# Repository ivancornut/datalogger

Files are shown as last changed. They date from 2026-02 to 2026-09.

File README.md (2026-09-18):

# Open Ecophysio Dataloggers
A competitive datalogger for use in environmental science. It is well adapted for work in remote locations with little access to networks. 

The big version of the datalogger is made to run on 12 or 24V lead batteries. This version has options to switch 12V or 5V loads.

The small version can run on 3 or 4 AA NiMh cells. It is made in a way that ensures very low consumption during sleep (few µAs). This gurantees around a year of logging before needing a battery change. 

Both versions have:
- a micro-SD card slot
- a very low-drift RTC for precise time-keeping
- battery voltage monitoring
- polarity and over-current protection

The interfacing software is compatible with windows, macOS and linux computers. It is made to be as simple to use as possible.

  * [Hardware](#hardware)
    + [Full size datalogger](#full-size-datalogger)
    + [Micro sized datalogger](#micro-sized-datalogger)
  * [Software](#software)
    + [On the computer](#on-the-computer)
    + [On the datalogger](#on-the-datalogger)

## Hardware
### Full size datalogger
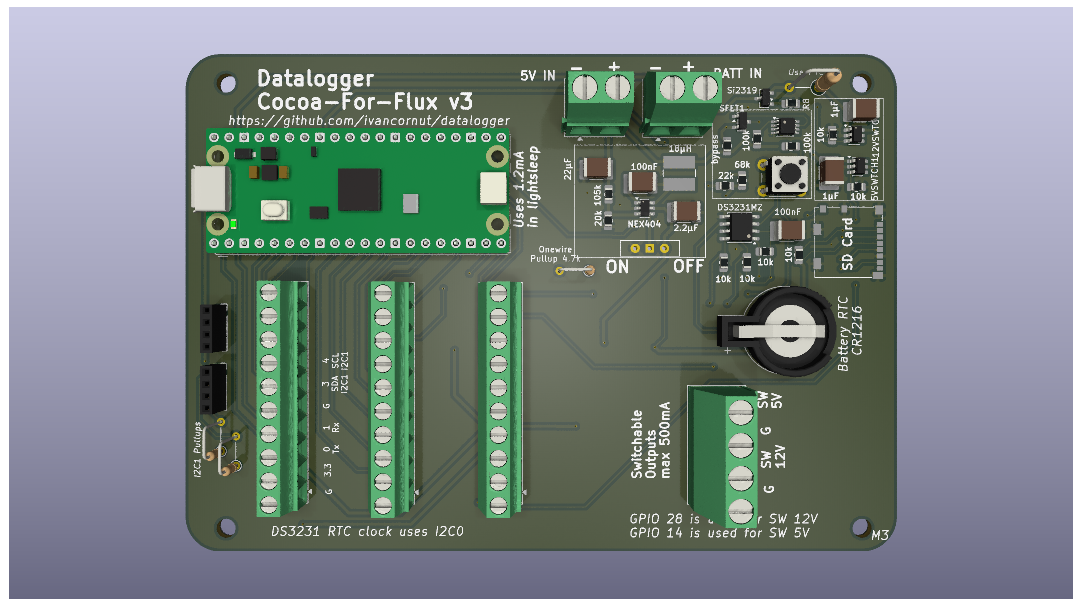
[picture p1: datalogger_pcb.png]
Finished datalogger PCB

We use a custom made PCB that integrates
- A battery input (usable with 12V lead batteries)
- a low consumption and high efficiency step-down converter that can convert 6-40V down to 5V
- a low-drift RTC clock
- An SD card slot
- two controllable power outputs of 5V and 12V (or battery voltage) using MOSFETs
- temperature corrected reference frequency generators from the RTC chip
- Qwiic compatible I2C and UART connectors
- A way to measure input battery voltage
### Micro sized datalogger
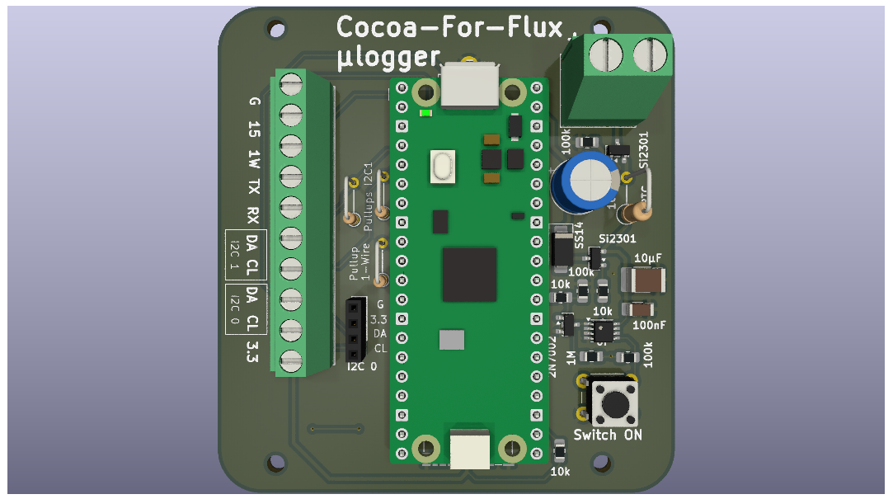
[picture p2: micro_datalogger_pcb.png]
3D rendering of datalogger PCB

This is a miniaturized version of the big pcb when size is a constraint. It pushed all the power and clock circuitry beneath the Pi Pico.
It lacks some functionality of the bigger version such as the controllable power outputs and the full shutdown circuitry. 

## Software
### On the computer
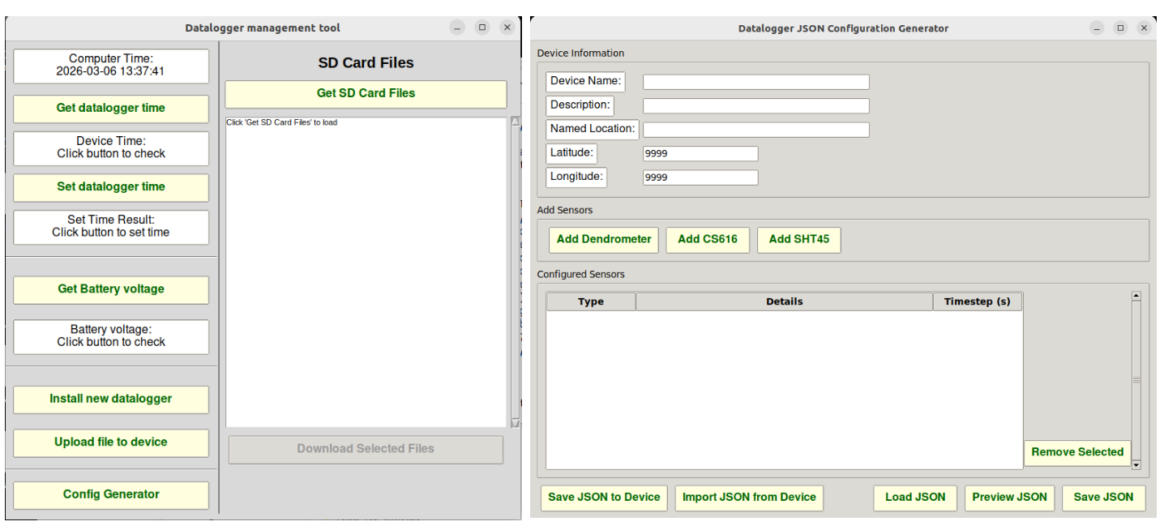
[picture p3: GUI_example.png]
Examples of interefacing GUIs

We use two GUIs on the computer:
- one that generates the json configuration file for the datalogger
- one that enables communication with the datalogger to update the clock and download files from the SD card

The datalogger management GUI also allows you to setup the datalogger with all the necessary libraries and config files to start datalogging right away.
#### Windows installation of the management GUI
The graphical user interface to perform some interfacing functions was made to be as easy to use as possible. For windows an executable file was created by using the pyinstaller library. 

To run on windows you first need to install python on your computer. You can install it easily from the windows store.
Then open up the powershell:
```
pip install mpremote
```
That should do the trick and you can just run the full_management_gui.exe in the Software/computer folder. 
#### Linux machine
You just need to install the mpremote tool. 
```
pip install mpremote
```
And then go to the folder containing full_management_gui.py: 
```
python full_management_gui.py
```

### On the datalogger
We use two modules. The datalogger module and the sensor module.

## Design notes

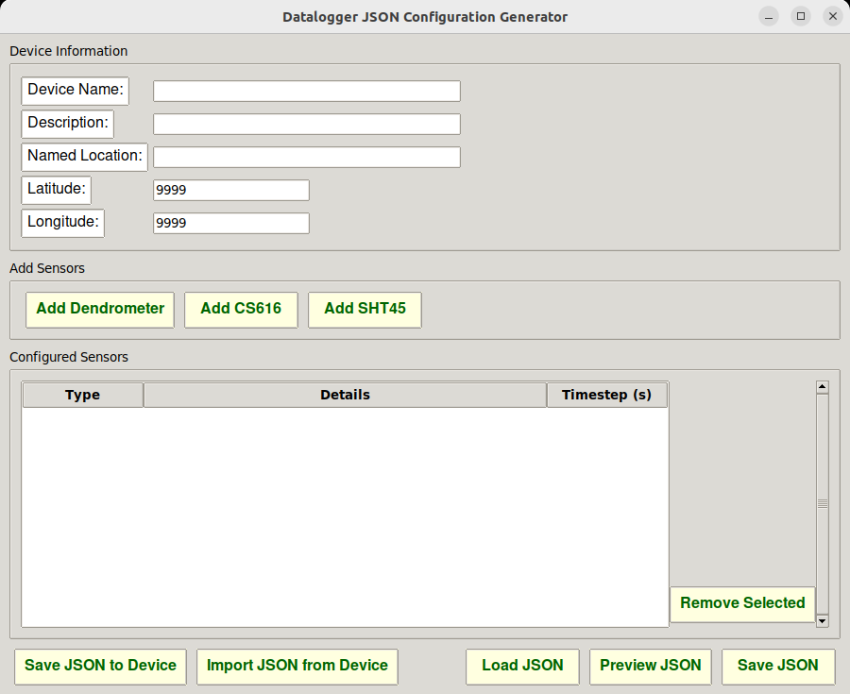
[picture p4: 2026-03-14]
config_ex.png

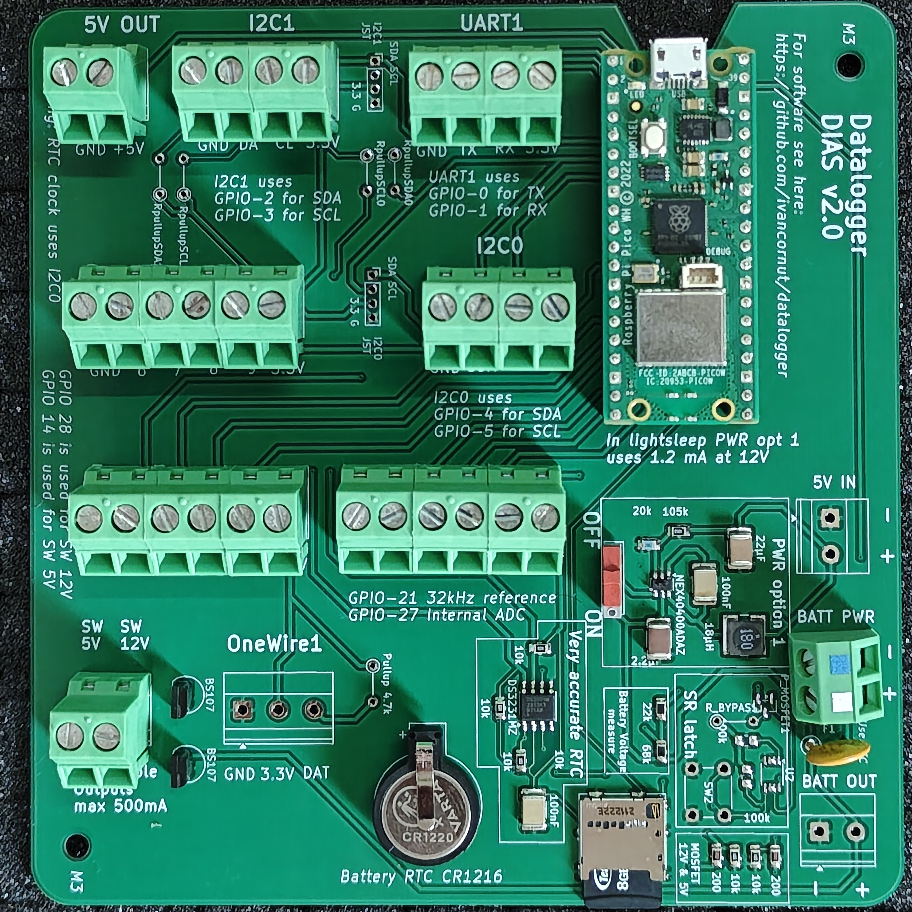
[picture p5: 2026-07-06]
datalogger_real.jpg

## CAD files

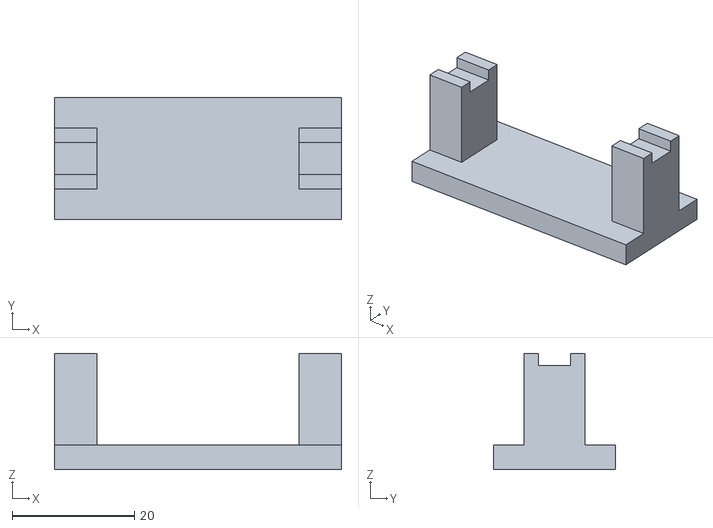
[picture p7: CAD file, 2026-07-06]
Hardware/sensors/temperature/temp_small/programmer_holder.stl
47.0 x 20.0 x 19.0

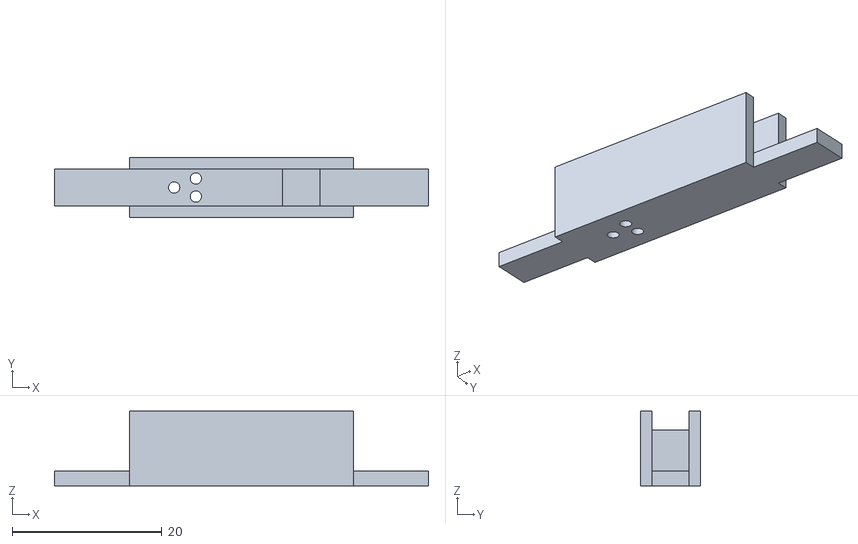
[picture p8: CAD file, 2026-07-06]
Hardware/sensors/temperature/temp_small/programmer.stl
50.0 x 8.00 x 10.0

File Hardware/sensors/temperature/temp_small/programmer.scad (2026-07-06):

include <BOSL2/std.scad>
difference(){
    union(){
    translate([0,0,10/2-1]){
        difference(){
            cuboid([30,8,10]);
            translate([0,0,2]){
                cuboid([31,5,10]);
            }
        }
    }
    cuboid([50,5,2]);
        translate([8,0,5.5/2+2/2]){
            cuboid([5,5,5.5]);
        }
    }
    translate([-9,0,0]){
        cyl(d = 1.5,h = 30,$fn = 100);
    }
    translate([-9+2.9,-2.4/2,0]){
        cyl(d = 1.5,h = 30,$fn = 100);
    }
    translate([-9+2.9,2.4/2,0]){
        cyl(d = 1.5,h = 30,$fn = 100);
    }
}

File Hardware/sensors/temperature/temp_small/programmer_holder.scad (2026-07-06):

include <BOSL2/std.scad>

union(){
    cuboid([47,20,4])
    translate([20,0,15/2+2]){
        difference(){
            cuboid([7,10,15]);
            translate([0,0,15/2-2/2]){
                cuboid([10,5.2,2]);
            }
        }
    }
    translate([-20,0,15/2+2]){
        difference(){
            cuboid([7,10,15]);
            translate([0,0,15/2-2/2]){
                cuboid([10,5.2,2]);
            }
        }
    }
}

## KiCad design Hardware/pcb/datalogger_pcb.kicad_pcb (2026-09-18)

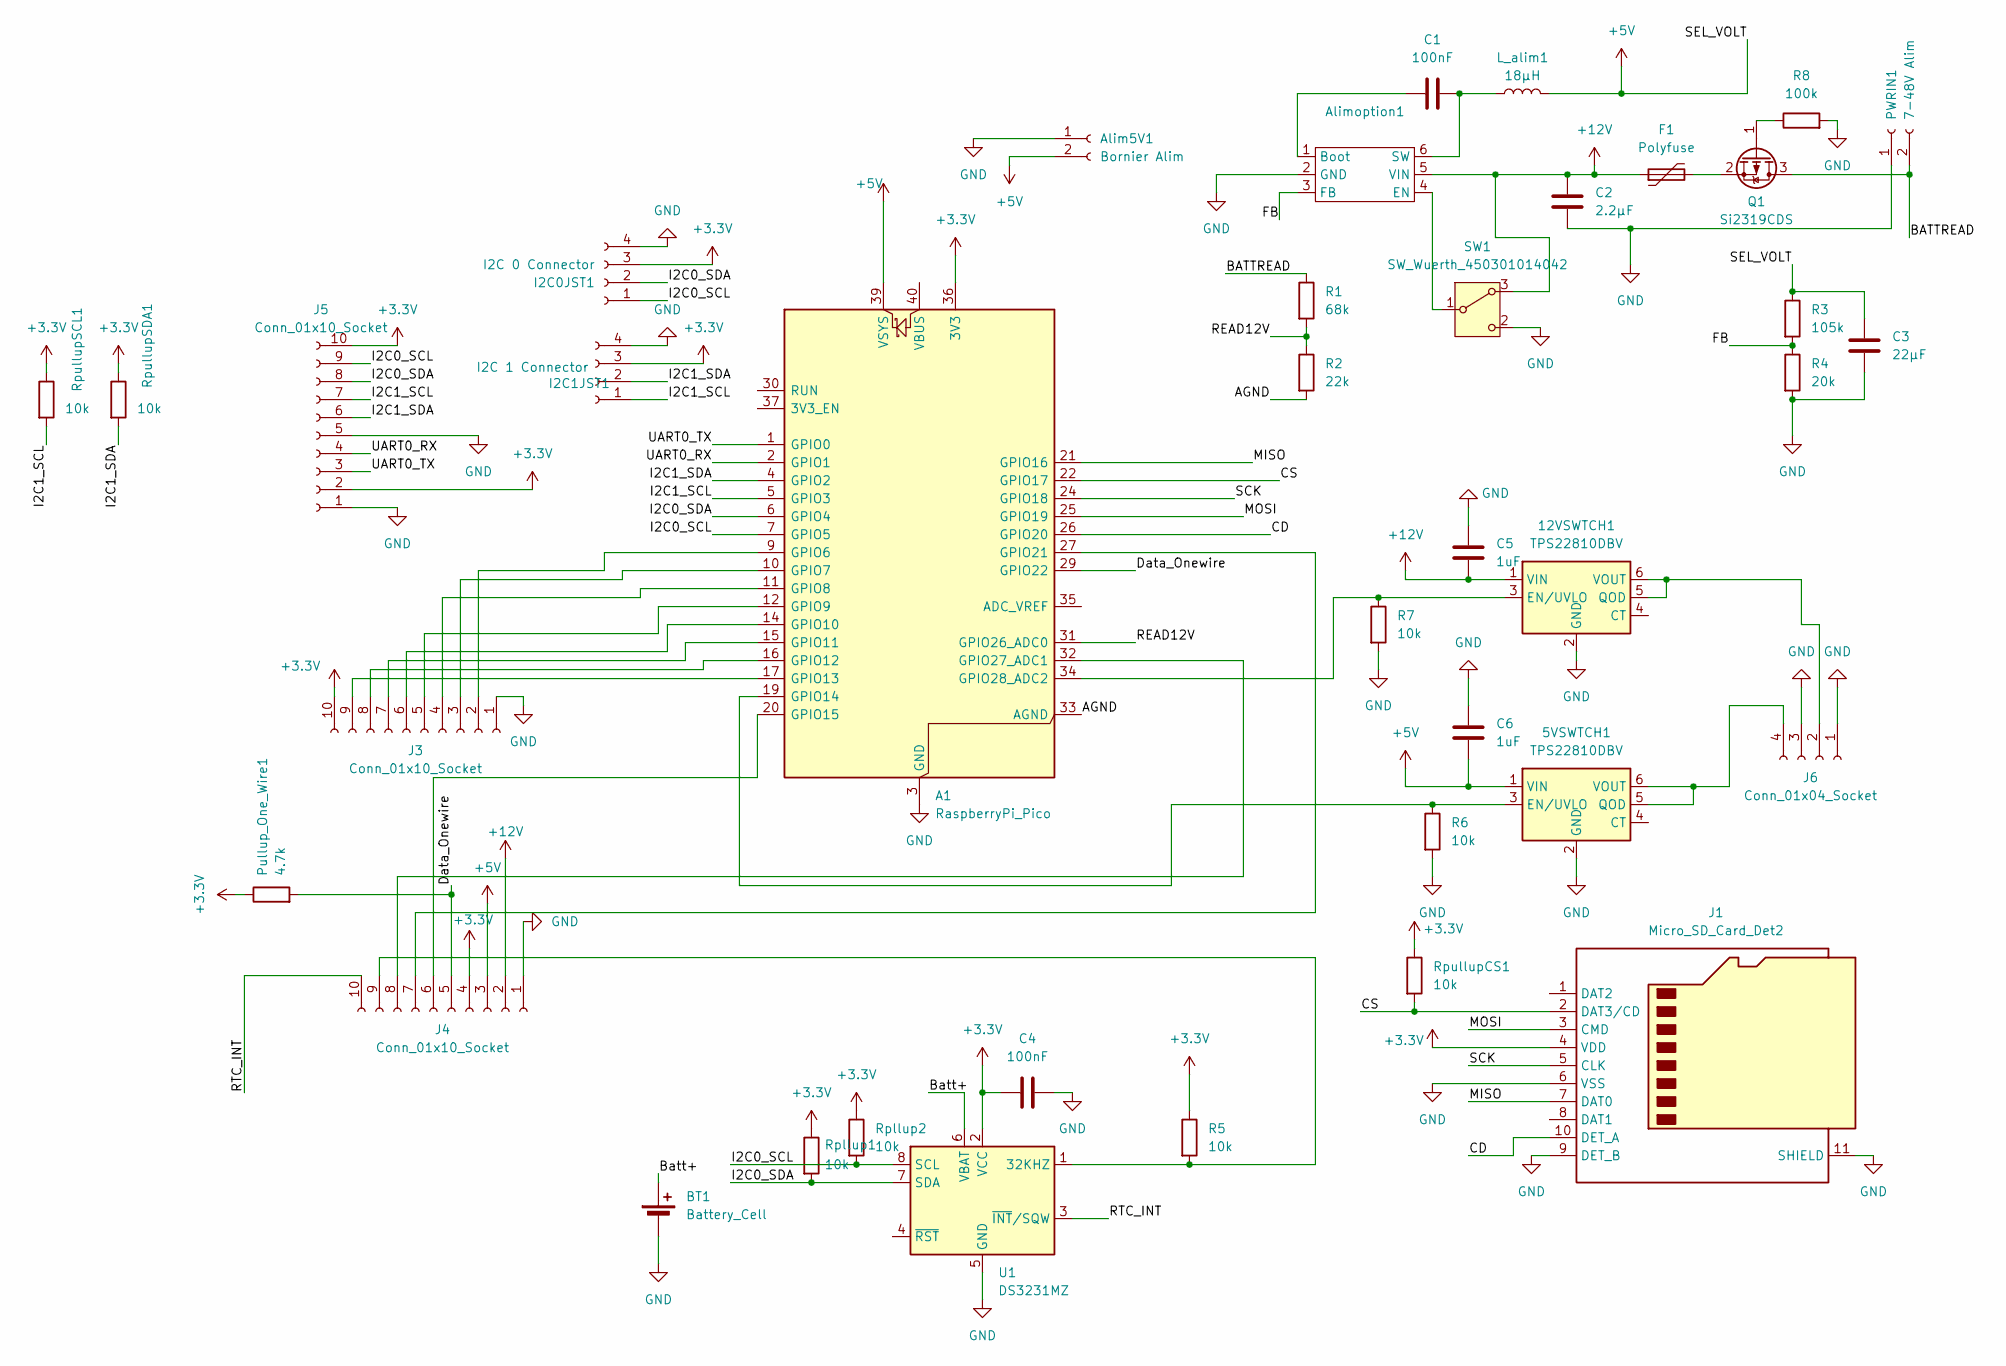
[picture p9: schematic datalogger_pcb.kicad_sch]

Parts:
5VSWTCH1, 12VSWTCH1: TPS22810DBV; SOT-23-6
A1: RaspberryPi_Pico; pi_pico_only_pins
Alim5V1: Bornier Alim; TerminalBlock_Phoenix_MKDS-1,5-2-5.08_1x02_P5.08mm_Horizont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
Alimoption1: TSOT-23-6_NEX
BT1: Battery_Cell; BatteryHolder_Keystone_500
C1, C4: 100nF; C_1812_4532Metric_Pad1.57x3.40mm_HandSolder
C2: 2.2µF; C_1812_4532Metric_Pad1.57x3.40mm_HandSolder
C3: 22µF; C_1812_4532Metric_Pad1.57x3.40mm_HandSolder
C5, C6: 1uF; C_1812_4532Metric_Pad1.57x3.40mm_HandSolder
F1: Polyfuse; R_Axial_DIN0207_L6.3mm_D2.5mm_P5.08mm_Vertical
I2C0JST1: I2C 0 Connector; PinSocket_1x04_P2.00mm_Vertical
I2C1JST1: I2C 1 Connector; PinSocket_1x04_P2.00mm_Vertical
J1: Micro_SD_Card_Det2; microSD_HC_Molex_104031-0811
J3, J4, J5: Conn_01x10_Socket; TerminalBlock_Phoenix_MKDS-1-10-3.81_1x10_P3.81mm_Horizontal
J6: Conn_01x04_Socket; TerminalBlock_Phoenix_MKDS-1,5-4-5.08_1x04_P5.08mm_Horizont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
L_alim1: 18µH; L_TracoPower_TCK-047_5.2x5.8mm
PWRIN1: 7-48V Alim; TerminalBlock_Phoenix_MKDS-1,5-2-5.08_1x02_P5.08mm_Horizont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
Pullup_One_Wire1: 4.7k; R_Axial_DIN0204_L3.6mm_D1.6mm_P5.08mm_Vertical
Q1: Si2319CDS; SOT-23
R1: 68k; R_0805_2012Metric_Pad1.20x1.40mm_HandSolder
R2: 22k; R_0805_2012Metric_Pad1.20x1.40mm_HandSolder
R3: 105k; R_0805_2012Metric_Pad1.20x1.40mm_HandSolder
R4: 20k; R_0805_2012Metric_Pad1.20x1.40mm_HandSolder
R5, R6, R7: 10k; R_0805_2012Metric_Pad1.20x1.40mm_HandSolder
R8: 100k; R_0805_2012Metric_Pad1.20x1.40mm_HandSolder
Rpllup1, Rpllup2: 10k; R_0805_2012Metric_Pad1.20x1.40mm_HandSolder
RpullupCS1: 10k; R_0805_2012Metric_Pad1.20x1.40mm_HandSolder
RpullupSCL1: 10k; R_Axial_DIN0204_L3.6mm_D1.6mm_P5.08mm_Vertical
RpullupSDA1: 10k; R_Axial_DIN0204_L3.6mm_D1.6mm_P5.08mm_Vertical
SW1: SW_Wuerth_450301014042; SW_Slide-03_Wuerth-WS-SLTV_10x2.5x6.4_P2.54mm
U1: DS3231MZ; SOIC-8_3.9x4.9mm_P1.27mm

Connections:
+3.3V: A1.36 (3V3), C4.1, I2C0JST1.3, I2C1JST1.3, J1.4 (VDD), J3.10, J4.4, J5.2, J5.10, Pullup_One_Wire1.1, R5.1, Rpllup1.1, Rpllup2.1, RpullupCS1.1, RpullupSCL1.1, RpullupSDA1.1, U1.2 (VCC)
+5V: 5VSWTCH1.1 (VIN), A1.39 (VSYS), Alim5V1.2, C3.1, C6.2, J4.3, L_alim1.2, R3.1
+12V: 12VSWTCH1.1 (VIN), Alimoption1.5 (VIN), C2.1, C5.2, F1.1, J4.2, SW1.3 (A)
/AGND: A1.33 (AGND), R2.2
/BATTREAD: PWRIN1.2, Q1.3 (D), R1.1
/Batt+: BT1.1 (+), U1.6 (VBAT)
/CD: A1.26 (GPIO20), J1.10 (DET_A)
/CS: A1.22 (GPIO17), J1.2 (DAT3/CD), RpullupCS1.2
/Data_Onewire: A1.29 (GPIO22), J4.5, Pullup_One_Wire1.2
/FB: Alimoption1.3 (FB), R3.2, R4.1
/I2C0_SCL: A1.7 (GPIO5), I2C0JST1.1, J5.9, Rpllup2.2, U1.8 (SCL)
/I2C0_SDA: A1.6 (GPIO4), I2C0JST1.2, J5.8, Rpllup1.2, U1.7 (SDA)
/I2C1_SCL: A1.5 (GPIO3), I2C1JST1.1, J5.7, RpullupSCL1.2
/I2C1_SDA: A1.4 (GPIO2), I2C1JST1.2, J5.6, RpullupSDA1.2
/MISO: A1.21 (GPIO16), J1.7 (DAT0)
/MOSI: A1.25 (GPIO19), J1.3 (CMD)
/READ12V: A1.31 (GPIO26_ADC0), R1.2, R2.1
/RTC_INT: J4.10, U1.3 (~INT/SQW)
/SCK: A1.24 (GPIO18), J1.5 (CLK)
/UART0_RX: A1.2 (GPIO1), J5.4
/UART0_TX: A1.1 (GPIO0), J5.3
GND: 5VSWTCH1.2 (GND), 12VSWTCH1.2 (GND), A1.3 (GND), A1.8 (GND), A1.13 (GND), A1.18 (GND), A1.23 (GND), A1.28 (GND), A1.38 (GND), Alim5V1.1, Alimoption1.2 (GND), BT1.2 (-), C2.2, C3.2, C4.2, C5.1, C6.1, I2C0JST1.4, I2C1JST1.4, J1.6 (VSS), J1.9 (DET_B), J1.11 (SHIELD), J3.1, J4.1, J5.1, J5.5, J6.1, J6.3, PWRIN1.1, R4.2, R6.2, R7.2, R8.2, SW1.2 (C), U1.5 (GND)
unnamed: 5VSWTCH1.3 (EN/UVLO), A1.19 (GPIO14), R6.1
unnamed: 5VSWTCH1.5 (QOD), 5VSWTCH1.6 (VOUT), J6.4
unnamed: 12VSWTCH1.3 (EN/UVLO), A1.34 (GPIO28_ADC2), R7.1
unnamed: 12VSWTCH1.5 (QOD), 12VSWTCH1.6 (VOUT), J6.2
unnamed: A1.9 (GPIO6), J3.2
unnamed: A1.10 (GPIO7), J3.3
unnamed: A1.11 (GPIO8), J3.4
unnamed: A1.12 (GPIO9), J3.5
unnamed: A1.14 (GPIO10), J3.6
unnamed: A1.15 (GPIO11), J3.7
unnamed: A1.16 (GPIO12), J3.8
unnamed: A1.17 (GPIO13), J3.9
unnamed: A1.20 (GPIO15), J4.6
unnamed: A1.27 (GPIO21), J4.7
unnamed: A1.32 (GPIO27_ADC1), J4.8
unnamed: Alimoption1.1 (Boot), C1.1
unnamed: Alimoption1.4 (EN), SW1.1 (B)
unnamed: Alimoption1.6 (SW), C1.2, L_alim1.1
unnamed: J4.9, R5.2, U1.1 (32KHZ)
unnamed: Q1.1 (G), R8.1
unnamed: F1.2, Q1.2 (S)

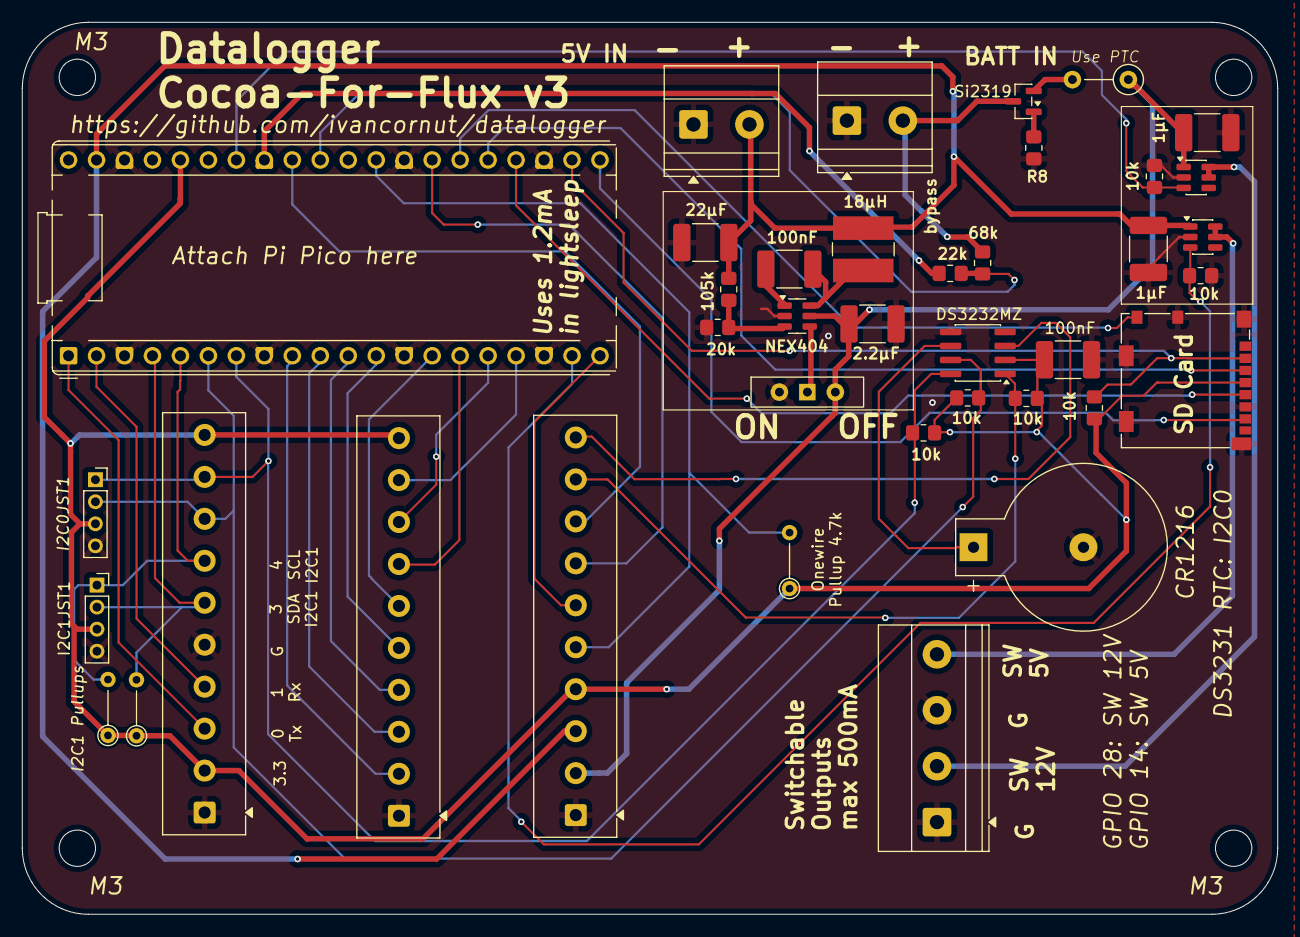
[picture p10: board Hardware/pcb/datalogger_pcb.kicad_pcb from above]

Board: 2 copper layers, 114.0 x 81.0 mm, 39 parts (0 on the bottom side), 43 nets.

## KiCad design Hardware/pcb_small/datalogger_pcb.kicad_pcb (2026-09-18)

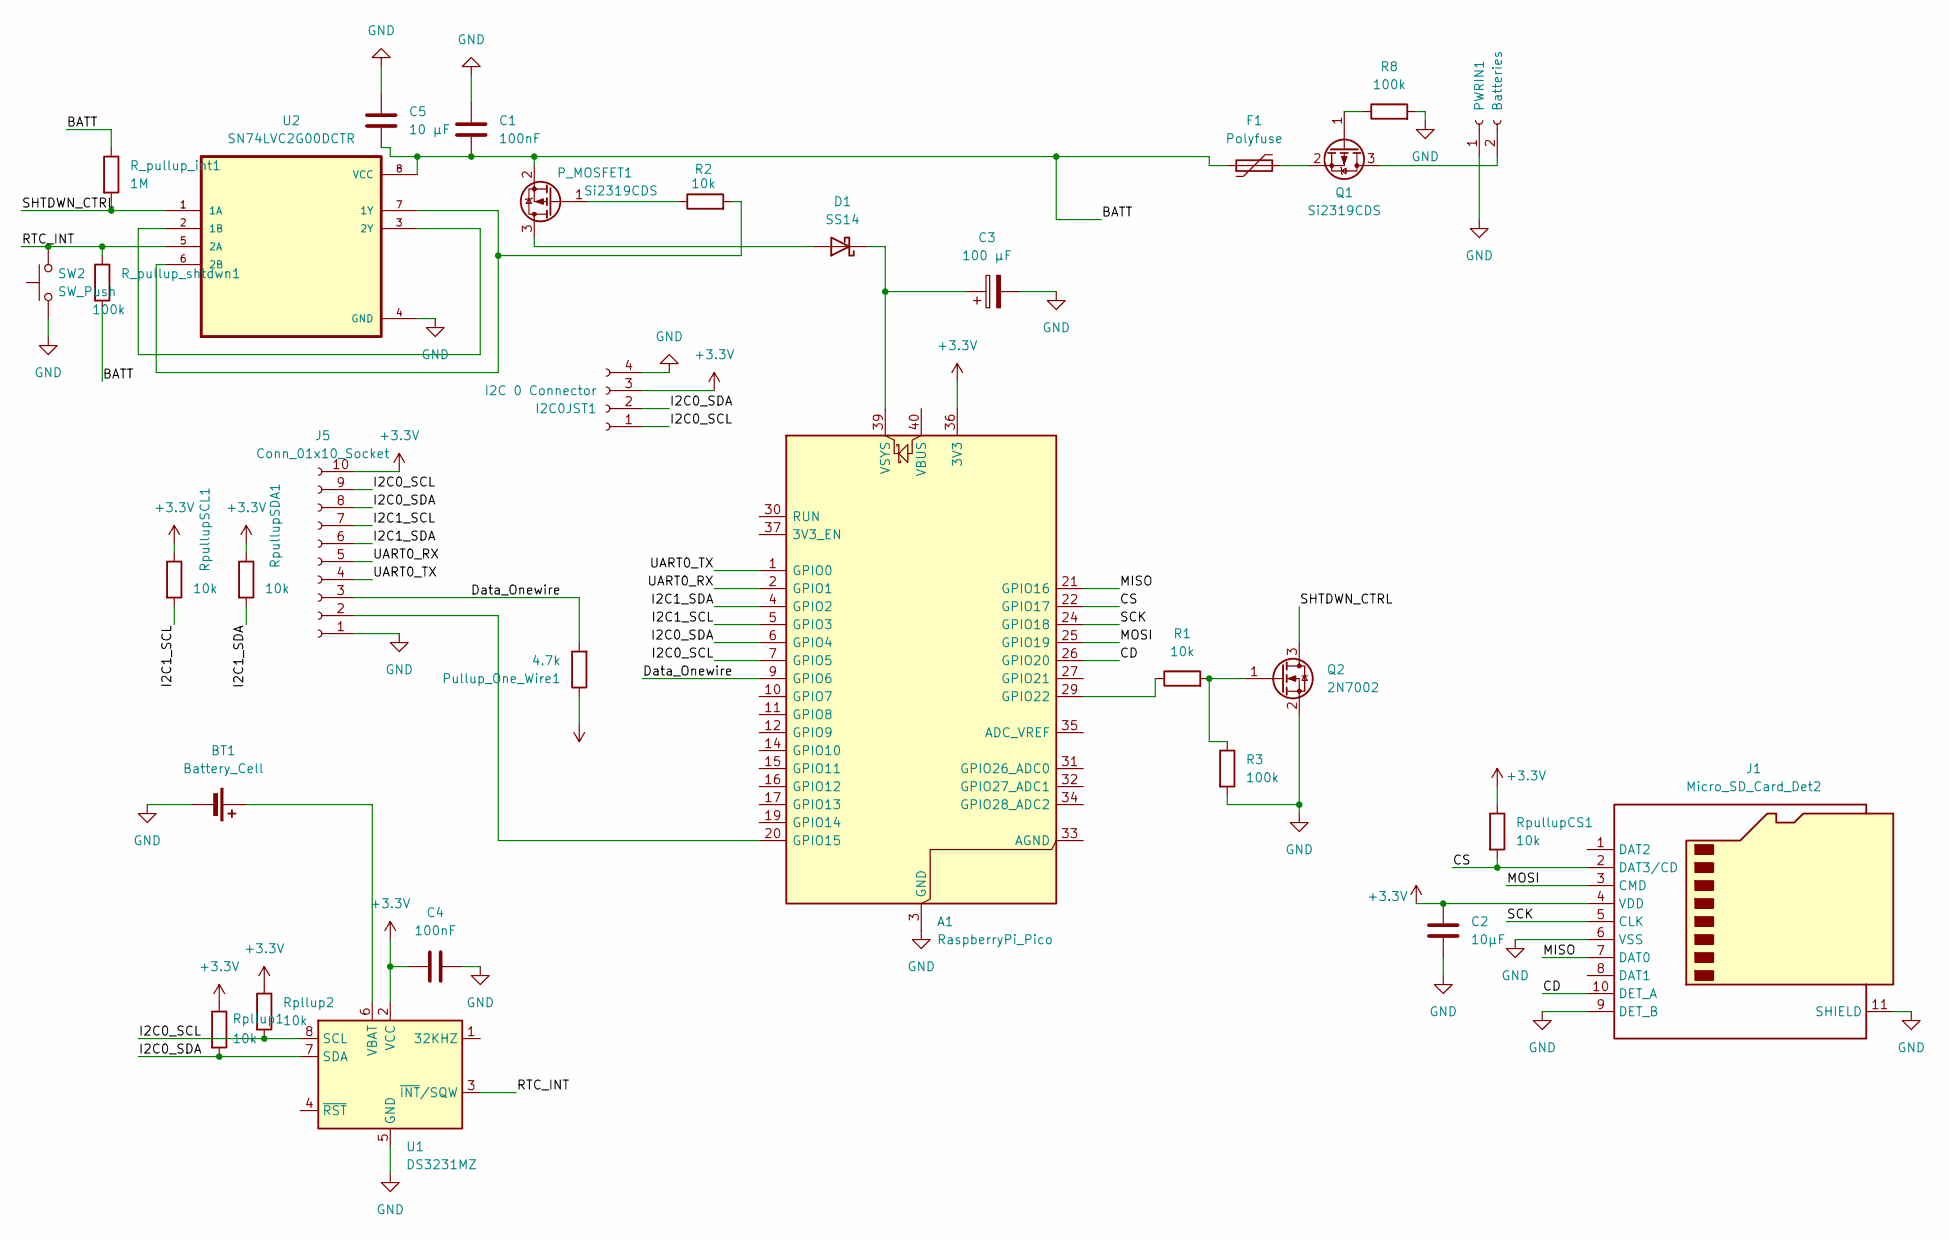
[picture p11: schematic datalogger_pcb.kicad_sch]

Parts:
A1: RaspberryPi_Pico; pi_pico_only_pins
BT1: Battery_Cell; BatteryHolder_Keystone_500
C1, C4: 100nF; C_1206_3216Metric_Pad1.33x1.80mm_HandSolder
C2: 10µF; C_1812_4532Metric_Pad1.57x3.40mm_HandSolder
C3: 100 µF; CP_Radial_D7.5mm_P2.50mm
C5: 10 µF; C_1812_4532Metric_Pad1.57x3.40mm_HandSolder
D1: SS14; D_SMA
F1: Polyfuse; R_Axial_DIN0207_L6.3mm_D2.5mm_P5.08mm_Vertical
I2C0JST1: I2C 0 Connector; PinSocket_1x04_P2.00mm_Vertical
J1: Micro_SD_Card_Det2; microSD_HC_Molex_104031-0811
J5: Conn_01x10_Socket; TerminalBlock_Phoenix_MKDS-1-10-3.81_1x10_P3.81mm_Horizontal
PWRIN1: Batteries; TerminalBlock_Phoenix_MKDS-1,5-2-5.08_1x02_P5.08mm_Horizont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
P_MOSFET1: Si2319CDS; SOT-23
Pullup_One_Wire1: 4.7k; R_Axial_DIN0204_L3.6mm_D1.6mm_P5.08mm_Vertical
Q1: Si2319CDS; SOT-23
Q2: 2N7002; SOT-23
R1, R2: 10k; R_0805_2012Metric_Pad1.20x1.40mm_HandSolder
R3, R8: 100k; R_0805_2012Metric_Pad1.20x1.40mm_HandSolder
R_pullup_int1: 1M; R_0805_2012Metric_Pad1.20x1.40mm_HandSolder
R_pullup_shtdwn1: 100k; R_0805_2012Metric_Pad1.20x1.40mm_HandSolder
Rpllup1, Rpllup2: 10k; R_0805_2012Metric_Pad1.20x1.40mm_HandSolder
RpullupCS1: 10k; R_0805_2012Metric_Pad1.20x1.40mm_HandSolder
RpullupSCL1: 10k; R_Axial_DIN0204_L3.6mm_D1.6mm_P5.08mm_Vertical
RpullupSDA1: 10k; R_Axial_DIN0204_L3.6mm_D1.6mm_P5.08mm_Vertical
SW2: SW_Push; SW_PUSH_6mm_H4.3mm
U1: DS3231MZ; SOIC-8_3.9x4.9mm_P1.27mm
U2: SN74LVC2G00DCTR; SSOP-8_2.95x2.8mm_P0.65mm - SN74LVC2G00

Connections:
+3.3V: A1.36 (3V3), C2.1, C4.1, I2C0JST1.3, J1.4 (VDD), J5.10, Pullup_One_Wire1.1, Rpllup1.1, Rpllup2.1, RpullupCS1.1, RpullupSCL1.1, RpullupSDA1.1, U1.2 (VCC)
/BATT: C1.1, C5.1, F1.1, P_MOSFET1.2 (S), R_pullup_int1.1, R_pullup_shtdwn1.2, U2.8 (VCC)
/CD: A1.26 (GPIO20), J1.10 (DET_A)
/CS: A1.22 (GPIO17), J1.2 (DAT3/CD), RpullupCS1.2
/Data_Onewire: A1.9 (GPIO6), J5.3, Pullup_One_Wire1.2
/I2C0_SCL: A1.7 (GPIO5), I2C0JST1.1, J5.9, Rpllup2.2, U1.8 (SCL)
/I2C0_SDA: A1.6 (GPIO4), I2C0JST1.2, J5.8, Rpllup1.2, U1.7 (SDA)
/I2C1_SCL: A1.5 (GPIO3), J5.7, RpullupSCL1.2
/I2C1_SDA: A1.4 (GPIO2), J5.6, RpullupSDA1.2
/MISO: A1.21 (GPIO16), J1.7 (DAT0)
/MOSI: A1.25 (GPIO19), J1.3 (CMD)
/RTC_INT: R_pullup_shtdwn1.1, SW2.2, U1.3 (~INT/SQW), U2.5 (2A)
/SCK: A1.24 (GPIO18), J1.5 (CLK)
/SHTDWN_CTRL: Q2.3 (D), R_pullup_int1.2, U2.1 (1A)
/UART0_RX: A1.2 (GPIO1), J5.5
/UART0_TX: A1.1 (GPIO0), J5.4
GND: A1.3 (GND), A1.8 (GND), A1.13 (GND), A1.18 (GND), A1.23 (GND), A1.28 (GND), A1.38 (GND), BT1.2 (-), C1.2, C2.2, C3.2, C4.2, C5.2, I2C0JST1.4, J1.6 (VSS), J1.9 (DET_B), J1.11 (SHIELD), J5.1, PWRIN1.1, Q2.2 (S), R3.2, R8.2, SW2.1, U1.5 (GND), U2.4 (GND)
unnamed: A1.20 (GPIO15), J5.2
unnamed: A1.29 (GPIO22), R1.1
unnamed: A1.39 (VSYS), C3.1, D1.1 (K)
unnamed: BT1.1 (+), U1.6 (VBAT)
unnamed: D1.2 (A), P_MOSFET1.3 (D)
unnamed: PWRIN1.2, Q1.3 (D)
unnamed: P_MOSFET1.1 (G), R2.1
unnamed: Q1.1 (G), R8.1
unnamed: F1.2, Q1.2 (S)
unnamed: Q2.1 (G), R1.2, R3.1
unnamed: U2.2 (1B), U2.3 (2Y)
unnamed: R2.2, U2.6 (2B), U2.7 (1Y)

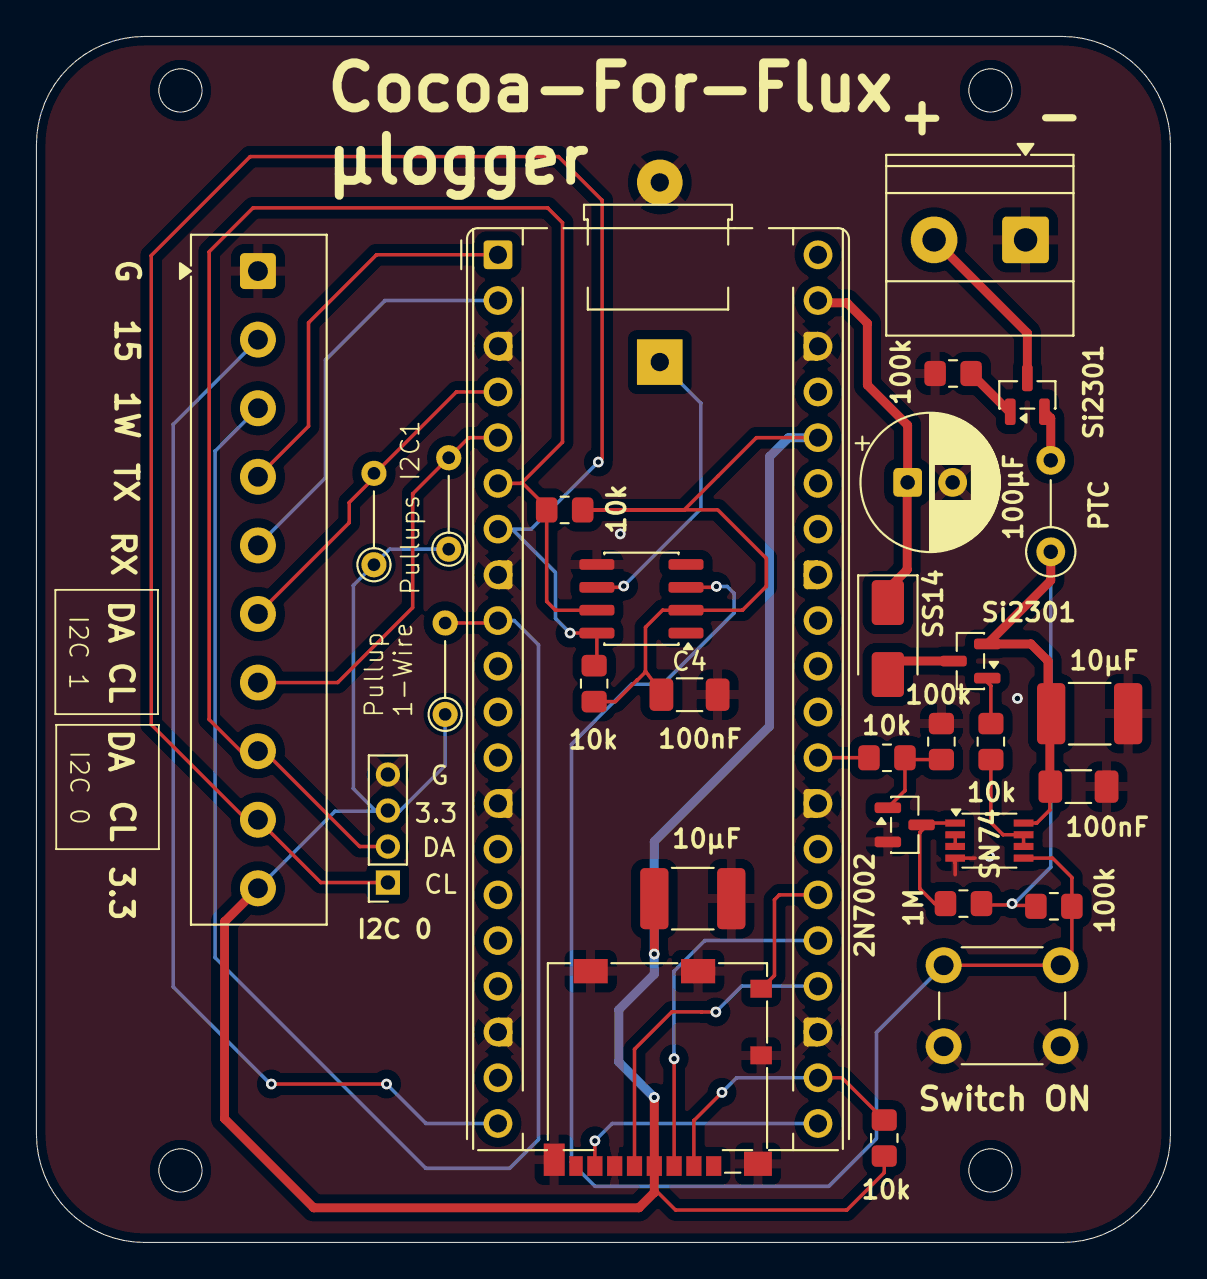
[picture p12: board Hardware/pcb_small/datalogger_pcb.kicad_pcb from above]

Board: 2 copper layers, 63.0 x 67.0 mm, 31 parts (1 on the bottom side), 29 nets.

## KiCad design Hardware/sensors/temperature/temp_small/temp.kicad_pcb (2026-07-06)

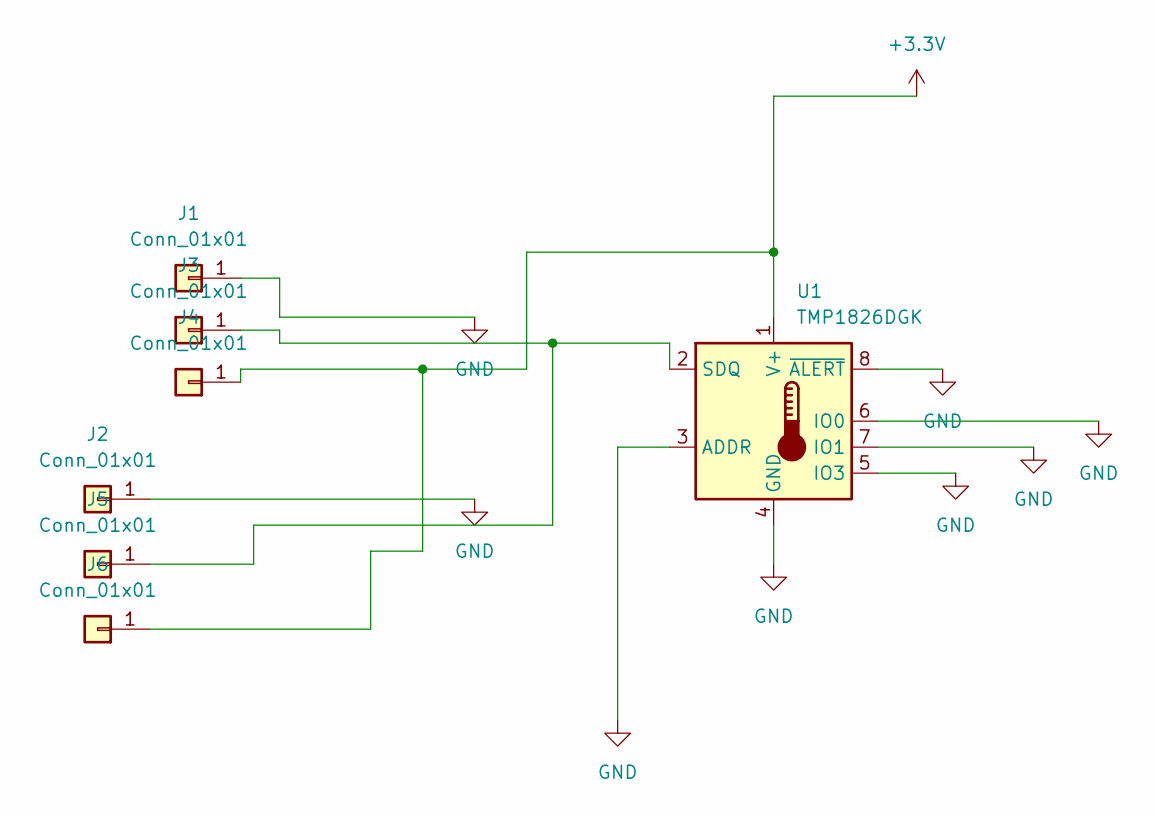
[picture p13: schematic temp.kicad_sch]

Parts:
J1, J2, J3, J4, J5, J6: Conn_01x01; PinHeader_1x01_P1.27mm_Vertical
U1: TMP1826DGK; VSSOP-8_3x3mm_P0.65mm

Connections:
+3.3V: J4.1, J6.1, U1.1 (V+)
GND: J1.1, J2.1, U1.3 (ADDR), U1.4 (GND), U1.5 (IO3), U1.6 (IO0), U1.7 (IO1), U1.8 (~ALERT)
unnamed: J3.1, J5.1, U1.2 (SDQ)

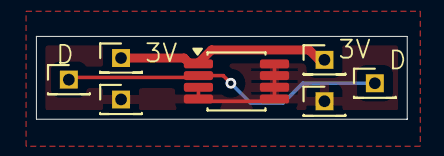
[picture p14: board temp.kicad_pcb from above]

Board: 2 copper layers, 20.6 x 4.6 mm, 7 parts (0 on the bottom side), 3 nets.

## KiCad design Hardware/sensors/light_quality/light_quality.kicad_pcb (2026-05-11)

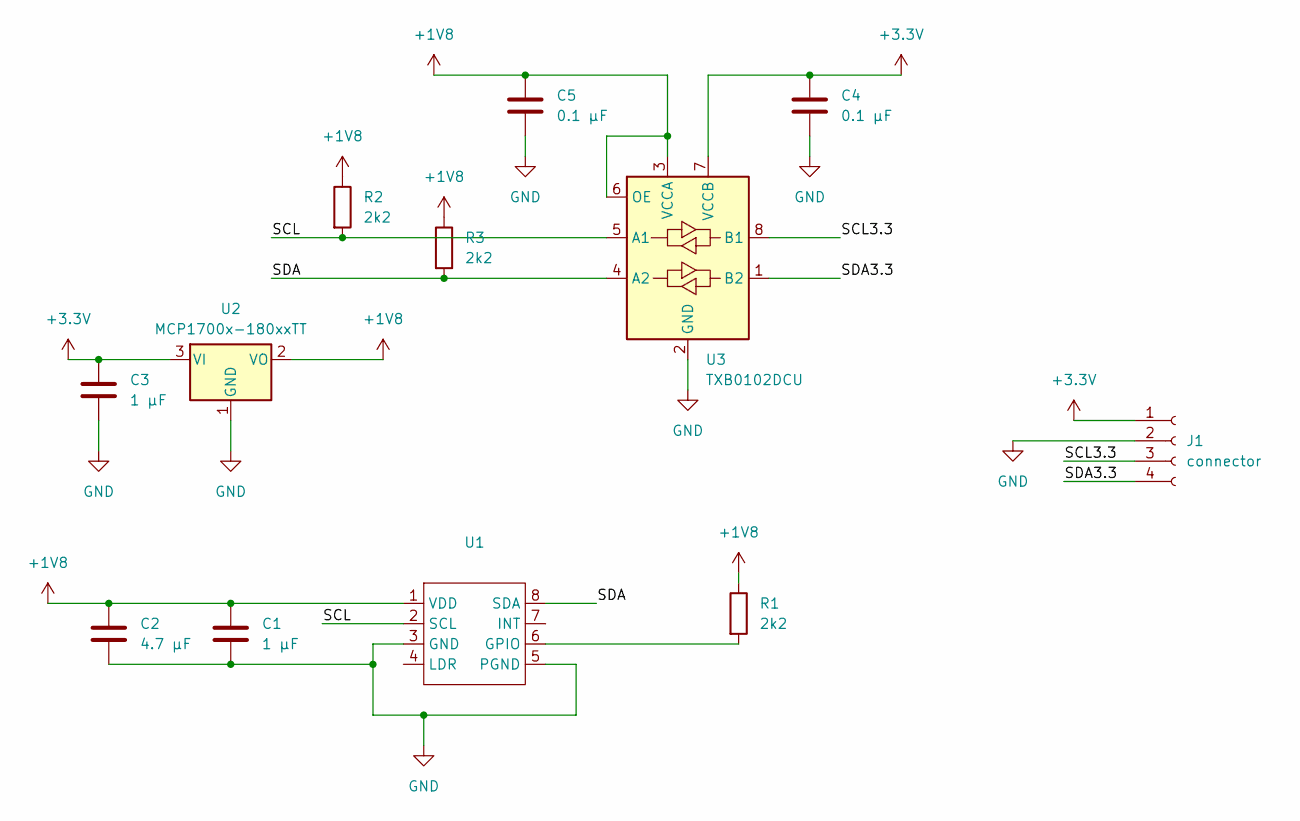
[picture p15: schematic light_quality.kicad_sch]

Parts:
C1, C3: 1 µF; C_0805_2012Metric_Pad1.18x1.45mm_HandSolder
C2: 4.7 µF; C_0805_2012Metric_Pad1.18x1.45mm_HandSolder
C4, C5: 0.1 µF; C_0805_2012Metric_Pad1.18x1.45mm_HandSolder
J1: connector; PinSocket_1x04_P2.00mm_Vertical
R1, R2, R3: 2k2; R_0805_2012Metric_Pad1.20x1.40mm_HandSolder
U1: AMS_OLGA-8_2x3.1mm_P0.8mm
U2: MCP1700x-180xxTT; SOT-23
U3: TXB0102DCU; VSSOP-8_2.3x2mm_P0.5mm

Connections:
+1V8: C1.1, C2.1, C5.1, R1.1, R2.1, R3.1, U1.1 (VDD), U2.2 (VO), U3.3 (VCCA), U3.6 (OE)
+3.3V: C3.1, C4.1, J1.1, U2.3 (VI), U3.7 (VCCB)
/SCL: R2.2, U1.2 (SCL), U3.5 (A1)
/SCL3.3: J1.3, U3.8 (B1)
/SDA: R3.2, U1.8 (SDA), U3.4 (A2)
/SDA3.3: J1.4, U3.1 (B2)
GND: C1.2, C2.2, C3.2, C4.2, C5.2, J1.2, U1.3 (GND), U1.5 (PGND), U2.1 (GND), U3.2 (GND)
unnamed: R1.2, U1.6 (GPIO)

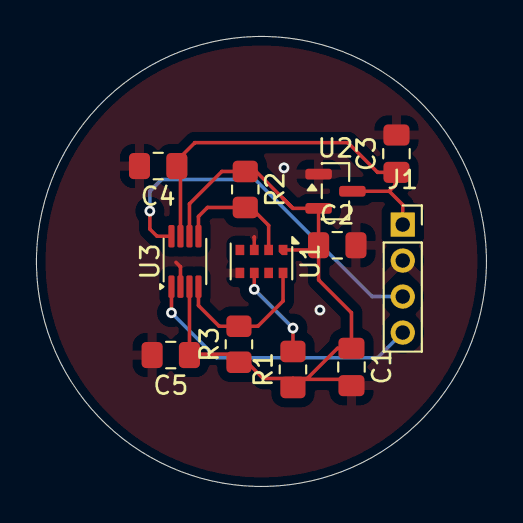
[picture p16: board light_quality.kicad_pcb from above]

Board: 2 copper layers, 25.0 x 25.0 mm, 12 parts (0 on the bottom side), 8 nets.

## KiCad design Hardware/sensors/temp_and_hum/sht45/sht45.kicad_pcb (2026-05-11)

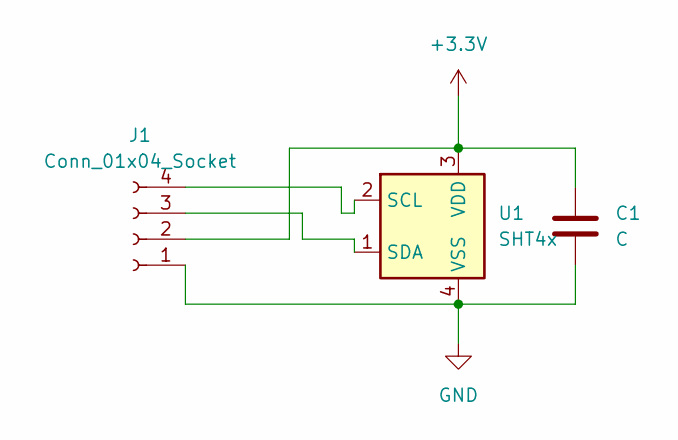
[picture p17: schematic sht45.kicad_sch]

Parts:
C1: C; C_0805_2012Metric_Pad1.18x1.45mm_HandSolder
J1: Conn_01x04_Socket; NS-Tech_Grove_1x04_P2mm_Vertical
U1: SHT4x; Sensirion_DFN-4_1.5x1.5mm_P0.8mm_SHT4x_NoCentralPad

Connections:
+3.3V: C1.1, J1.2, U1.3 (VDD)
GND: C1.2, J1.1, U1.4 (VSS)
unnamed: J1.3, U1.1 (SDA)
unnamed: J1.4, U1.2 (SCL)

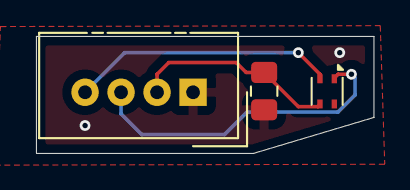
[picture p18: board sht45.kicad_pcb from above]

Board: 2 copper layers, 18.8 x 6.5 mm, 3 parts (0 on the bottom side), 4 nets.

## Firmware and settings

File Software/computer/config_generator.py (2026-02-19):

#!/usr/bin/env python3
"""
Datalogger JSON Configuration Generator
A tkinter GUI for creating JSON configuration files for dataloggers.
"""

import tkinter as tk
from tkinter import ttk, messagebox, filedialog
import json


class SensorDialog(tk.Toplevel):
    """Base class for sensor configuration dialogs."""
    
    def __init__(self, parent, title):
        super().__init__(parent)
        self.title(title)
        self.result = None
        self.transient(parent)
        self.grab_set()
        
        # Center the dialog
        self.geometry("+%d+%d" % (parent.winfo_rootx() + 50, parent.winfo_rooty() + 50))
        
        self.create_widgets()
        
        self.protocol("WM_DELETE_WINDOW", self.cancel)
        self.wait_window(self)
    
    def create_widgets(self):
        """Override in subclasses."""
        pass
    
    def validate(self):
        """Override in subclasses."""
        return True
    
    def ok(self):
        if self.validate():
            self.destroy()
    
    def cancel(self):
        self.result = None
        self.destroy()


class DendroDialog(SensorDialog):
    """Dialog for configuring dendrometer sensors."""
    
    def __init__(self, parent):
        self.name_entries = []
        self.excite_entries = []
        super().__init__(parent, "Add Dendrometer Sensor")
    
    def create_widgets(self):
        main_frame = ttk.Frame(self, padding="10")
        main_frame.pack(fill=tk.BOTH, expand=True)
        
        # I2C selection
        ttk.Label(main_frame, text="I2C Bus:").grid(row=0, column=0, sticky=tk.W, pady=2)
        self.i2c_var = tk.IntVar(value=0)
        i2c_frame = ttk.Frame(main_frame)
        i2c_frame.grid(row=0, column=1, sticky=tk.W, pady=2)
        ttk.Radiobutton(i2c_frame, text="0", variable=self.i2c_var, value=0).pack(side=tk.LEFT)
        ttk.Radiobutton(i2c_frame, text="1", variable=self.i2c_var, value=1).pack(side=tk.LEFT)
        
        # Address
        ttk.Label(main_frame, text="Address (decimal, e.g. 72):").grid(row=1, column=0, sticky=tk.W, pady=2)
        self.address_entry = ttk.Entry(main_frame, width=20)
        self.address_entry.grid(row=1, column=1, sticky=tk.W, pady=2)
        self.address_entry.insert(0, "72")
        
        # Number of dendrometers
        ttk.Label(main_frame, text="Number (1 or 2):").grid(row=2, column=0, sticky=tk.W, pady=2)
        self.number_var = tk.IntVar(value=1)
        number_frame = ttk.Frame(main_frame)
        number_frame.grid(row=2, column=1, sticky=tk.W, pady=2)
        ttk.Radiobutton(number_frame, text="1", variable=self.number_var, value=1, 
                       command=self.update_dynamic_fields).pack(side=tk.LEFT)
        ttk.Radiobutton(number_frame, text="2", variable=self.number_var, value=2,
                       command=self.update_dynamic_fields).pack(side=tk.LEFT)
        
        # Timestep
        ttk.Label(main_frame, text="Timestep (seconds):").grid(row=3, column=0, sticky=tk.W, pady=2)
        self.timestep_entry = ttk.Entry(main_frame, width=20)
        self.timestep_entry.grid(row=3, column=1, sticky=tk.W, pady=2)
        self.timestep_entry.insert(0, "10")
        
        # Dynamic frame for excite pins and names
        self.dynamic_frame = ttk.LabelFrame(main_frame, text="Dendrometer Configuration", padding="5")
        self.dynamic_frame.grid(row=4, column=0, columnspan=2, sticky=tk.EW, pady=10)
        
        self.update_dynamic_fields()
        
        # Buttons
        btn_frame = ttk.Frame(main_frame)
        btn_frame.grid(row=5, column=0, columnspan=2, pady=10)
        ttk.Button(btn_frame, text="OK", command=self.ok).pack(side=tk.LEFT, padx=5)
        ttk.Button(btn_frame, text="Cancel", command=self.cancel).pack(side=tk.LEFT, padx=5)
    
    def update_dynamic_fields(self):
        # Clear existing widgets
        for widget in self.dynamic_frame.winfo_children():
            widget.destroy()
        
        self.name_entries = []
        self.excite_entries = []
        
        num = self.number_var.get()
        
        for i in range(num):
            row_frame = ttk.Frame(self.dynamic_frame)
            row_frame.pack(fill=tk.X, pady=2)
            
            ttk.Label(row_frame, text=f"Dendro {i+1} Name:").pack(side=tk.LEFT)
            name_entry = ttk.Entry(row_frame, width=15)
            name_entry.pack(side=tk.LEFT, padx=5)
            name_entry.insert(0, f"dendro_{i+1}")
            self.name_entries.append(name_entry)
            
            ttk.Label(row_frame, text="Excite Pin:").pack(side=tk.LEFT, padx=(10, 0))
            excite_entry = ttk.Entry(row_frame, width=8)
            excite_entry.pack(side=tk.LEFT, padx=5)
            excite_entry.insert(0, str(6 + i))
            self.excite_entries.append(excite_entry)
    
    def validate(self):
        try:
            # Validate address (decimal number)
            address = int(self.address_entry.get().strip())
            
            # Validate timestep
            timestep = int(self.timestep_entry.get())
            if timestep <= 0:
                raise ValueError("Timestep must be positive")
            
            # Validate excite pins
            excite_pins = []
            for entry in self.excite_entries:
                excite_pins.append(int(entry.get()))
            
            # Collect names
            names = [entry.get().strip() for entry in self.name_entries]
            if any(not name for name in names):
                raise ValueError("All names must be filled")
            
            self.result = {
                "type": "dendro",
                "params": {
                    "I2C": self.i2c_var.get(),
                    "address": address,
                    "number": self.number_var.get(),
                    "excite": excite_pins,
                    "names": names
                },
                "timestep": timestep
            }
            return True
            
        except ValueError as e:
            messagebox.showerror("Validation Error", f"Invalid input: {e}")
            return False


class CS616Dialog(SensorDialog):
    """Dialog for configuring CS616 soil moisture sensors."""
    
    def __init__(self, parent):
        super().__init__(parent, "Add CS616 Sensor")
    
    def create_widgets(self):
        main_frame = ttk.Frame(self, padding="10")
        main_frame.pack(fill=tk.BOTH, expand=True)
        
        # Number
        ttk.Label(main_frame, text="Number (0-8):").grid(row=0, column=0, sticky=tk.W, pady=2)
        self.number_spinbox = ttk.Spinbox(main_frame, from_=0, to=8, width=10)
        self.number_spinbox.grid(row=0, column=1, sticky=tk.W, pady=2)
        self.number_spinbox.set(8)
        
        # Control Pins (3 pins)
        ttk.Label(main_frame, text="Control Pins (3 pins):").grid(row=1, column=0, sticky=tk.W, pady=2)
        ctrl_frame = ttk.Frame(main_frame)
        ctrl_frame.grid(row=1, column=1, sticky=tk.W, pady=2)
        
        self.ctrl_entries = []
        default_pins = [8, 9, 10]
        for i in range(3):
            entry = ttk.Entry(ctrl_frame, width=6)
            entry.pack(side=tk.LEFT, padx=2)
            entry.insert(0, str(default_pins[i]))
            self.ctrl_entries.append(entry)
        
        # Measurement Pin
        ttk.Label(main_frame, text="Measurement Pin:").grid(row=2, column=0, sticky=tk.W, pady=2)
        self.meas_entry = ttk.Entry(main_frame, width=10)
        self.meas_entry.grid(row=2, column=1, sticky=tk.W, pady=2)
        self.meas_entry.insert(0, "13")

        # Enable Pin
        ttk.Label(main_frame, text="Disable Pin:").grid(row=3, column=0, sticky=tk.W, pady=2)
        self.enab_entry = ttk.Entry(main_frame, width=10)
        self.enab_entry.grid(row=3, column=1, sticky=tk.W, pady=2)
        self.enab_entry.insert(0, "9")
        
        # Timestep
        ttk.Label(main_frame, text="Timestep (seconds):").grid(row=4, column=0, sticky=tk.W, pady=2)
        self.timestep_entry = ttk.Entry(main_frame, width=10)
        self.timestep_entry.grid(row=4, column=1, sticky=tk.W, pady=2)
        self.timestep_entry.insert(0, "10")
        
        # Buttons
        btn_frame = ttk.Frame(main_frame)
        btn_frame.grid(row=5, column=0, columnspan=2, pady=10)
        ttk.Button(btn_frame, text="OK", command=self.ok).pack(side=tk.LEFT, padx=5)
        ttk.Button(btn_frame, text="Cancel", command=self.cancel).pack(side=tk.LEFT, padx=5)
    
    def validate(self):
        try:
            number = int(self.number_spinbox.get())
            if not 0 <= number <= 8:
                raise ValueError("Number must be between 0 and 8")
            
            ctrl_pins = [int(entry.get()) for entry in self.ctrl_entries]
            meas_pin = int(self.meas_entry.get())
            disab_Pin = int(self.enab_entry.get())

            timestep = int(self.timestep_entry.get())
            if timestep <= 0:
                raise ValueError("Timestep must be positive")
            
            self.result = {
                "type": "CS616",
                "params": {
                    "number": number,
                    "ctrlPins": ctrl_pins,
                    "measPin": meas_pin,
                    "disabPin":disab_Pin
                },
                "timestep": timestep
            }
            return True
            
        except ValueError as e:
            messagebox.showerror("Validation Error", f"Invalid input: {e}")
            return False


class SHT45Dialog(SensorDialog):
    """Dialog for configuring SHT45 temperature/humidity sensors."""
    
    def __init__(self, parent):
        super().__init__(parent, "Add SHT45 Sensor")
    
    def create_widgets(self):
        main_frame = ttk.Frame(self, padding="10")
        main_frame.pack(fill=tk.BOTH, expand=True)
        
        # I2C selection
        ttk.Label(main_frame, text="I2C Bus:").grid(row=0, column=0, sticky=tk.W, pady=2)
        self.i2c_var = tk.IntVar(value=0)
        i2c_frame = ttk.Frame(main_frame)
        i2c_frame.grid(row=0, column=1, sticky=tk.W, pady=2)
        ttk.Radiobutton(i2c_frame, text="0", variable=self.i2c_var, value=0).pack(side=tk.LEFT)
        ttk.Radiobutton(i2c_frame, text="1", variable=self.i2c_var, value=1).pack(side=tk.LEFT)
        
        # Name
        ttk.Label(main_frame, text="Sensor Name:").grid(row=1, column=0, sticky=tk.W, pady=2)
        self.name_entry = ttk.Entry(main_frame, width=20)
        self.name_entry.grid(row=1, column=1, sticky=tk.W, pady=2)
        self.name_entry.insert(0, "Outside")
        
        # Timestep
        ttk.Label(main_frame, text="Timestep (seconds):").grid(row=2, column=0, sticky=tk.W, pady=2)
        self.timestep_entry = ttk.Entry(main_frame, width=10)
        self.timestep_entry.grid(row=2, column=1, sticky=tk.W, pady=2)
        self.timestep_entry.insert(0, "10")
        
        # Buttons
        btn_frame = ttk.Frame(main_frame)
        btn_frame.grid(row=3, column=0, columnspan=2, pady=10)
        ttk.Button(btn_frame, text="OK", command=self.ok).pack(side=tk.LEFT, padx=5)
        ttk.Button(btn_frame, text="Cancel", command=self.cancel).pack(side=tk.LEFT, padx=5)
    
    def validate(self):
        try:
            name = self.name_entry.get().strip()
            if not name:
                raise ValueError("Name cannot be empty")
            
            timestep = int(self.timestep_entry.get())
            if timestep <= 0:
                raise ValueError("Timestep must be positive")
            
            params = {"name": name}
            params["I2C"] = self.i2c_var.get()
            
            self.result = {
                "type": "SHT45",
                "params": params,
                "timestep": timestep
            }
            return True
            
        except ValueError as e:
            messagebox.showerror("Validation Error", f"Invalid input: {e}")
            return False
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

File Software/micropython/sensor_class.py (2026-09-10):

from time import  sleep_ms, sleep, ticks_us, ticks_ms, ticks_diff
import math
from machine import Pin
import binascii
import CD4051
from counter import PWMCounter
import onewire, ds18x20
import sht4x
import ads1x15
import tmp1826

def standard_deviation_calc(ind_val_array):
    sample_mean = 0
    if len(ind_val_array)>0:
        for i in ind_val_array:
            sample_mean = sample_mean + i/len(ind_val_array)
        sum_diffs = 0
        for i in ind_val_array:
            sum_diffs = sum_diffs + math.pow(i-sample_mean,2)
        variance = sum_diffs/len(ind_val_array)
        standard_deviation = math.sqrt(variance)
    else:
        standard_deviation = 9999

    return standard_deviation

def rerun_meas_loop(std,sample_mean,criteria):
    if sample_mean == 0:
        return False
    var_pct = std/sample_mean * 100
    print(f"Variance: %1.1f" % var_pct)
    if var_pct > criteria:
        return True
    else:
        return False


class temp_tmp1826:
    def __init__(self, meas_pin=12):
        self.exists = True
        try:
            self.dat_pin = Pin(meas_pin)
            self.ow = onewire.OneWire(self.dat_pin) # choose the adapted pin
            self.ow.reset() # reset the onewire bus (necessary)
            self.sensor = tmp1826.TMP1826(self.ow) # create the tmp1826 object
            self.roms = self.sensor.scan() # get all sensors
            self.sensor_dict = {}
            self.column_names = []
            sleep(0.25)
            for i in self.roms:
                label = self.sensor.read_label(i)
                self.sensor_dict[str(binascii.hexlify(i))] = label
                self.column_names.append("Temp_"+label)
        except Exception as e:
            print("Error in initialising tmp1826 sensor")
            self.column_names = []
            self.sensor_dict = {}
            print(e)
            self.exists = False

        self.error = False
        self.total_error = False

    def read_values(self,watchdog,internal_led, debug = False):
        data_values = []
        try:
            self.ow.reset() # reset the onewire bus (necessary)
            sleep(0.5)
            self.sensor.convert_temp()
            sleep(0.750)
            for i in self.roms:
                print("Sensor: "+self.sensor_dict[str(binascii.hexlify(i))])
                try:
                    data_values.append(self.sensor.read_temp(i, verbose = True))
                except Exception as e:
                    print("Error for this sensor")
                    print(e)
                    data_values.append(9999)
                sleep(0.05)
                watchdog.feed()
            return data_values
        except Exception as e:
            print("Major error in tmp1826 loop:")
            print(e)
            for i in self.roms:
                data_values.append(9999)
            return data_values

class temp_hum_sht45:
    def __init__(self,i2c_obj, name="SHT45"):
        self.error = False
        self.i2c_obj = i2c_obj
        try:
            self.sht = sht4x.SHT4X(self.i2c_obj)
            self.exists = True
        except Exception as e:
            print(e)
            self.exists = False
            with open('logs.txt','a') as f:
                f.write("Error init SHT45:")
                f.write(str(e))
                f.write("\n")
            print("Major Error in init SHT45")
        self.column_names  = [name+"_T_air",name+"_RH_air"]

    def read_values(self,watchdog, internal_led, debug = False):
        data_values = []
        try:
            temperature, relative_humidity = self.sht.measurements
        except Exception as e:
            print(e)
            temperature = 9999
            relative_humidity = 9999
            if not self.error:
                with open('logs.txt','a') as f:
                    f.write("Error read SHT45:")
                    f.write(str(e))
                    f.write("\n")
                self.error = True
        data_values.append(temperature)
        data_values.append(relative_humidity)
        watchdog.feed()
        print("SHT45 data:",data_values)

        return data_values

class TDR_CS616:
    def __init__(self, nb_cs616=8, meas_pin=11,ctrl_pins = [6,7,8], disable_pin=9,reps=5,corrected=False,rtc=None):
        #self.enable_Pin = Pin(enable_pin,Pin.OUT) # Pin to enable sensors with 5V
        #self.enable_Pin.value(0)
        self.disable_Pin = Pin(disable_pin,Pin.OUT) # Pin to disable sensors with 5V
        self.disable_Pin.value(1) # turn ON to disable

        self.switch_control = CD4051.CD4051(ctrl_pins[0],ctrl_pins[1],ctrl_pins[2]) # control of the first CD4051 switch

        self.reps = reps # number of repetitions

        # create the column names for each sensor
        self.column_names = []
        for i in range(0,nb_cs616):
            self.column_names.append("TDR"+str(i)+"_us")
            self.column_names.append("TDR"+str(i)+"_WC%")
        # handle the frequency counting Pin
        self.pin_counter = PWMCounter(meas_pin, PWMCounter.EDGE_RISING)
        self.pin_counter.set_div() # Set divisor to 1 (just in case)
        self.pin_counter.start() # Start counter
        self.pin_counter.stop() # Stop counter

        self.exists = True # allways exists since no way to check

        self.number = nb_cs616
        self.corrected = corrected

        if corrected:
            self.rtc = rtc
            self.rtc.output_32kHz(False)
            self.column_names.append("32kHz_correction")

    def _cs616_measure(self, watchdog):
        ''' The frequency measuring function
        the period of the CS616 is then used to deduce soil
        water content'''
        sampling_time = 100000
        mean_freq = 0
        self.pin_counter.stop()
        self.pin_counter.reset()

        outlier = True # to see if there is a major discrepancy between meass
        stop_loop = 0

        while outlier:
            ind_freqs = []
            mean_freq = 0
            for i in range(0,self.reps):
                cond = True
                last_check = ticks_us()
                self.pin_counter.start()
                while cond:
                    if ticks_diff(tmp := ticks_us(), last_check) >= sampling_time:
                        freq = self.pin_counter.read_and_reset() / (sampling_time / 1000000)
                        ind_freqs.append(freq)
                        mean_freq = mean_freq + (freq)/self.reps
                        cond = False
                self.pin_counter.stop()
                self.pin_counter.reset()
            stop_loop = stop_loop+1
            std_freq = standard_deviation_calc(ind_freqs)
            outlier = rerun_meas_loop(std_freq,mean_freq,2)
            if stop_loop > 3:
                mean_freq = 0
                outlier = False
            watchdog.feed()
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

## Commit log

2026-02-02 Added pcb files
    [datalogger_pcb-B_Cu.gbr, datalogger_pcb-B_Mask.gbr, datalogger_pcb-B_Paste.gbr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]
2026-02-02 Added pcb image
2026-02-17 Made cs616 work with new pcbs and disable pin
    [datalogger_pcb.kicad_pcb]
2026-02-19 Created small version of pcb
    [datalogger_pcb-B_Cu.gbr, datalogger_pcb-B_Mask.gbr, datalogger_pcb-B_Paste.gbr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]
2026-02-19 Finalised design for micrologger
    [datalogger_pcb.kicad_pcb, datalogger_pcb.kicad_sch]
2026-02-20 Corrected screw diameter error
    [datalogger_pcb.kicad_pcb, datalogger_pcb.kicad_sch]
2026-03-05 Added the libraries that are necessary on the pico
2026-03-18 Added daily machine reset to code to prevent shutdowns
    [TDR_Pit_1_2026-1-17.csv, TDR_Pit_1_2026-1-18.csv, TDR_Pit_1_2026-1-19.csv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]
2026-03-18 Changed file download from sd card
    [Dendros tour_2026-2-26.csv]
2026-03-18 New executable
    [Dendros tour_2026-2-26.csv, TDR_Pit_1_2026-1-17.csv, TDR_Pit_1_2026-1-18.csv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]
2026-04-22 Repaired critical bugs in micropython progs
    [datalogger_pcb.kicad_pcb]
2026-04-24 Changed way of resetting in datalogger manage
    [datalogger_manage.py]
2026-04-26 Added temperature 1-wire pcb
    [temp.kicad_pcb, temp.kicad_sch]
2026-04-26 improved temperature 1-wire pcb
    [temp.kicad_pcb, temp.kicad_sch]
2026-04-27 Added latching shutdown
    [datalogger_pcb.kicad_pcb, datalogger_pcb.kicad_sch]
2026-04-27 Smaller temp pcb
    [temp.kicad_pcb, temp.kicad_sch]
2026-05-11 Added PAR sensor PCB
    [datalogger_pcb.kicad_pcb, datalogger_pcb.kicad_sch, light_quality.kicad_pcb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]
2026-07-06 Corrected errors in PCB
    [datalogger_pcb-B_Cu.gbr, datalogger_pcb-B_Mask.gbr, datalogger_pcb-B_Silkscreen.gbr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]
2026-07-06 small changes
    [programmer.scad]
2026-07-16 Changed small error in jst SDA and SCL mixup
    [datalogger_pcb.kicad_pcb]
2026-07-27 Changes to PCB and new sensor TMP1826 added
    [datalogger_pcb.kicad_pcb]
2026-07-31 Improvements to PCB
    [datalogger_pcb.kicad_pcb, datalogger_pcb.kicad_sch]
2026-07-31 Repaired issues with tmp1826 sensor initialisation
    [datalogger_class.py, datalogger_class_old.py, read_rtc_time.py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]
2026-07-31 Improvements to PCB and code
    [datalogger_pcb.kicad_pcb]
2026-08-10 Improved datalogger design and reduced pcb size
    [datalogger_pcb.kicad_pcb, datalogger_pcb.kicad_sch]
2026-08-10 Change in pcb picture
    [datalogger_pcb.kicad_pcb]
2026-08-10 Made code as retro-compatible as possible
    [datalogger_pcb.kicad_pcb]
2026-08-12 Improvd pcb
    [datalogger_pcb.kicad_pcb]
2026-08-15 New smaller efficient pcb
    [datalogger_pcb.kicad_pcb, datalogger_pcb.kicad_sch]
2026-08-16 Changes in small pcb
    [datalogger_pcb.kicad_pcb, datalogger_pcb.kicad_sch]
2026-09-10 Changes to ulogger pcb
    [datalogger_pcb.kicad_pcb, datalogger_pcb.kicad_sch]
2026-09-18 Changes to small pcb
    [datalogger_pcb.kicad_pcb, datalogger_pcb.kicad_sch]
2026-09-18 Updated image of small pcb
